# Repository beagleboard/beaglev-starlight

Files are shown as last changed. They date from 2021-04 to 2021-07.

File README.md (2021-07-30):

## ARCHIVED: BeagleV™ - Starlight beta prototype
The BeagleV™ - Starlight project has concluded and no units beyond the beta prototypes will be produced.  This design was never sold as a product.  

**This repository is meant only for archival purposes.**  Please do not open any new issues.  

Please visit the [BeagleV™ community website](http://beaglev.org/) to learn about future RISC-V development boards.

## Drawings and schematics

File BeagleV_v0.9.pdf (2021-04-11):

# VIC Power

# PMIC

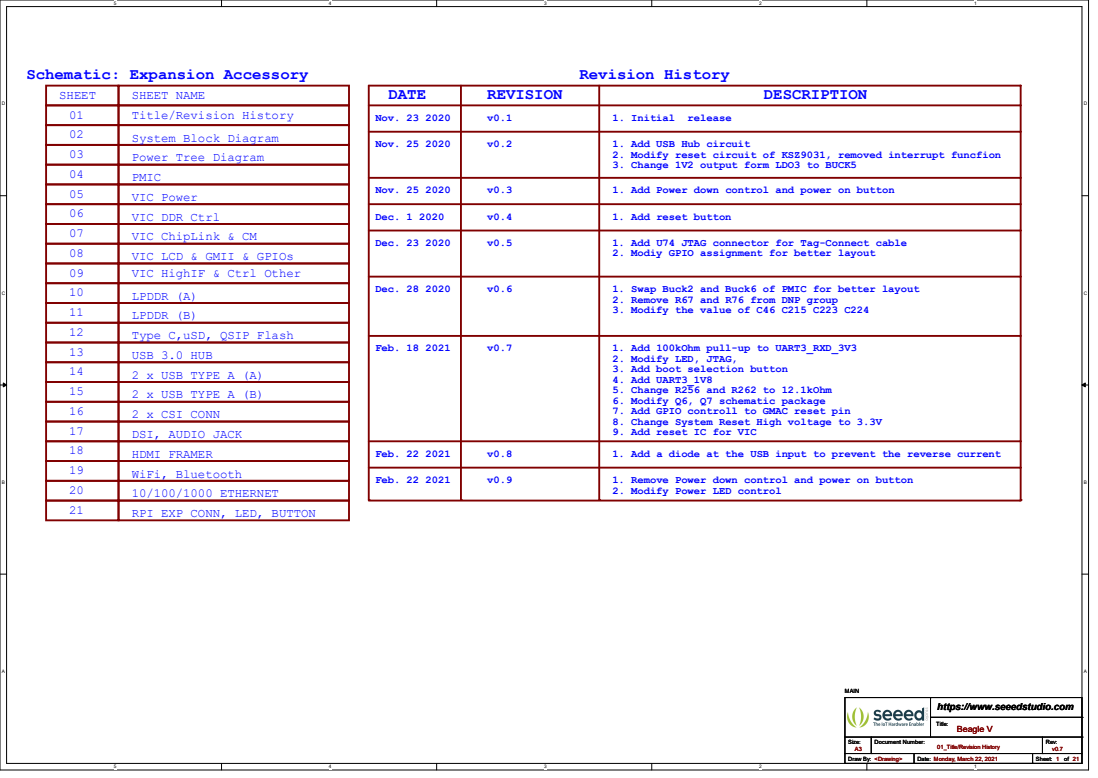
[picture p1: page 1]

Nov. 23 2020 | v0.1 | 1. Initial release

Nov. 25 2020 | v0.2 | 1. Add USB Hub circuit 2. Modify reset circuit of KSZ9031, removed interrupt funcfion 3. Change 1V2 output form LDO3 to BUCK5

Nov. 25 2020 | v0.3 | 1. Add Power down control and power on button

VIC DDR Ctrl
VIC ChipLink & CM
VIC LCD & GMII & GPIOs
VIC HighIF & Ctrl Other
LPDDR (A)
LPDDR (B)
Type C,uSD, QSIP Flash
USB 3.0 HUB
2 x USB TYPE A (A)
2 x USB TYPE A (B)
2 x CSI CONN
DSI, AUDIO JACK
HDMI FRAMER
WiFi, Bluetooth
10/100/1000 ETHERNET
RPI EXP CONN, LED, BUTTON

Dec. 1 2020 | v0.4 | 1. Add reset button

Dec. 23 2020 | v0.5 | 1. Add U74 JTAG connector for Tag-Connect cable 2. Modiy GPIO assignment for better layout

2. Remove R67 and R76 from DNP group
3. Modify the value of C46 C215 C223 C224

Feb. 18 2021 | v0.7 | 1. Add 100kOhm pull-up to UART3_RXD_3V3 2. Modify LED, JTAG, 3. Add boot selection button 4. Add UART3_1V8 5. Change R256 and R262 to 12.1kOhm 6. Modify Q6, Q7 schematic package 7. Add GPIO controll to GMAC reset pin 8. Change System Reset High voltage to 3.3V 9. Add reset IC for VIC

Feb. 22 2021 | v0.8 | 1. Add a diode at the USB input to prevent the reverse current

2. Modify Power LED control

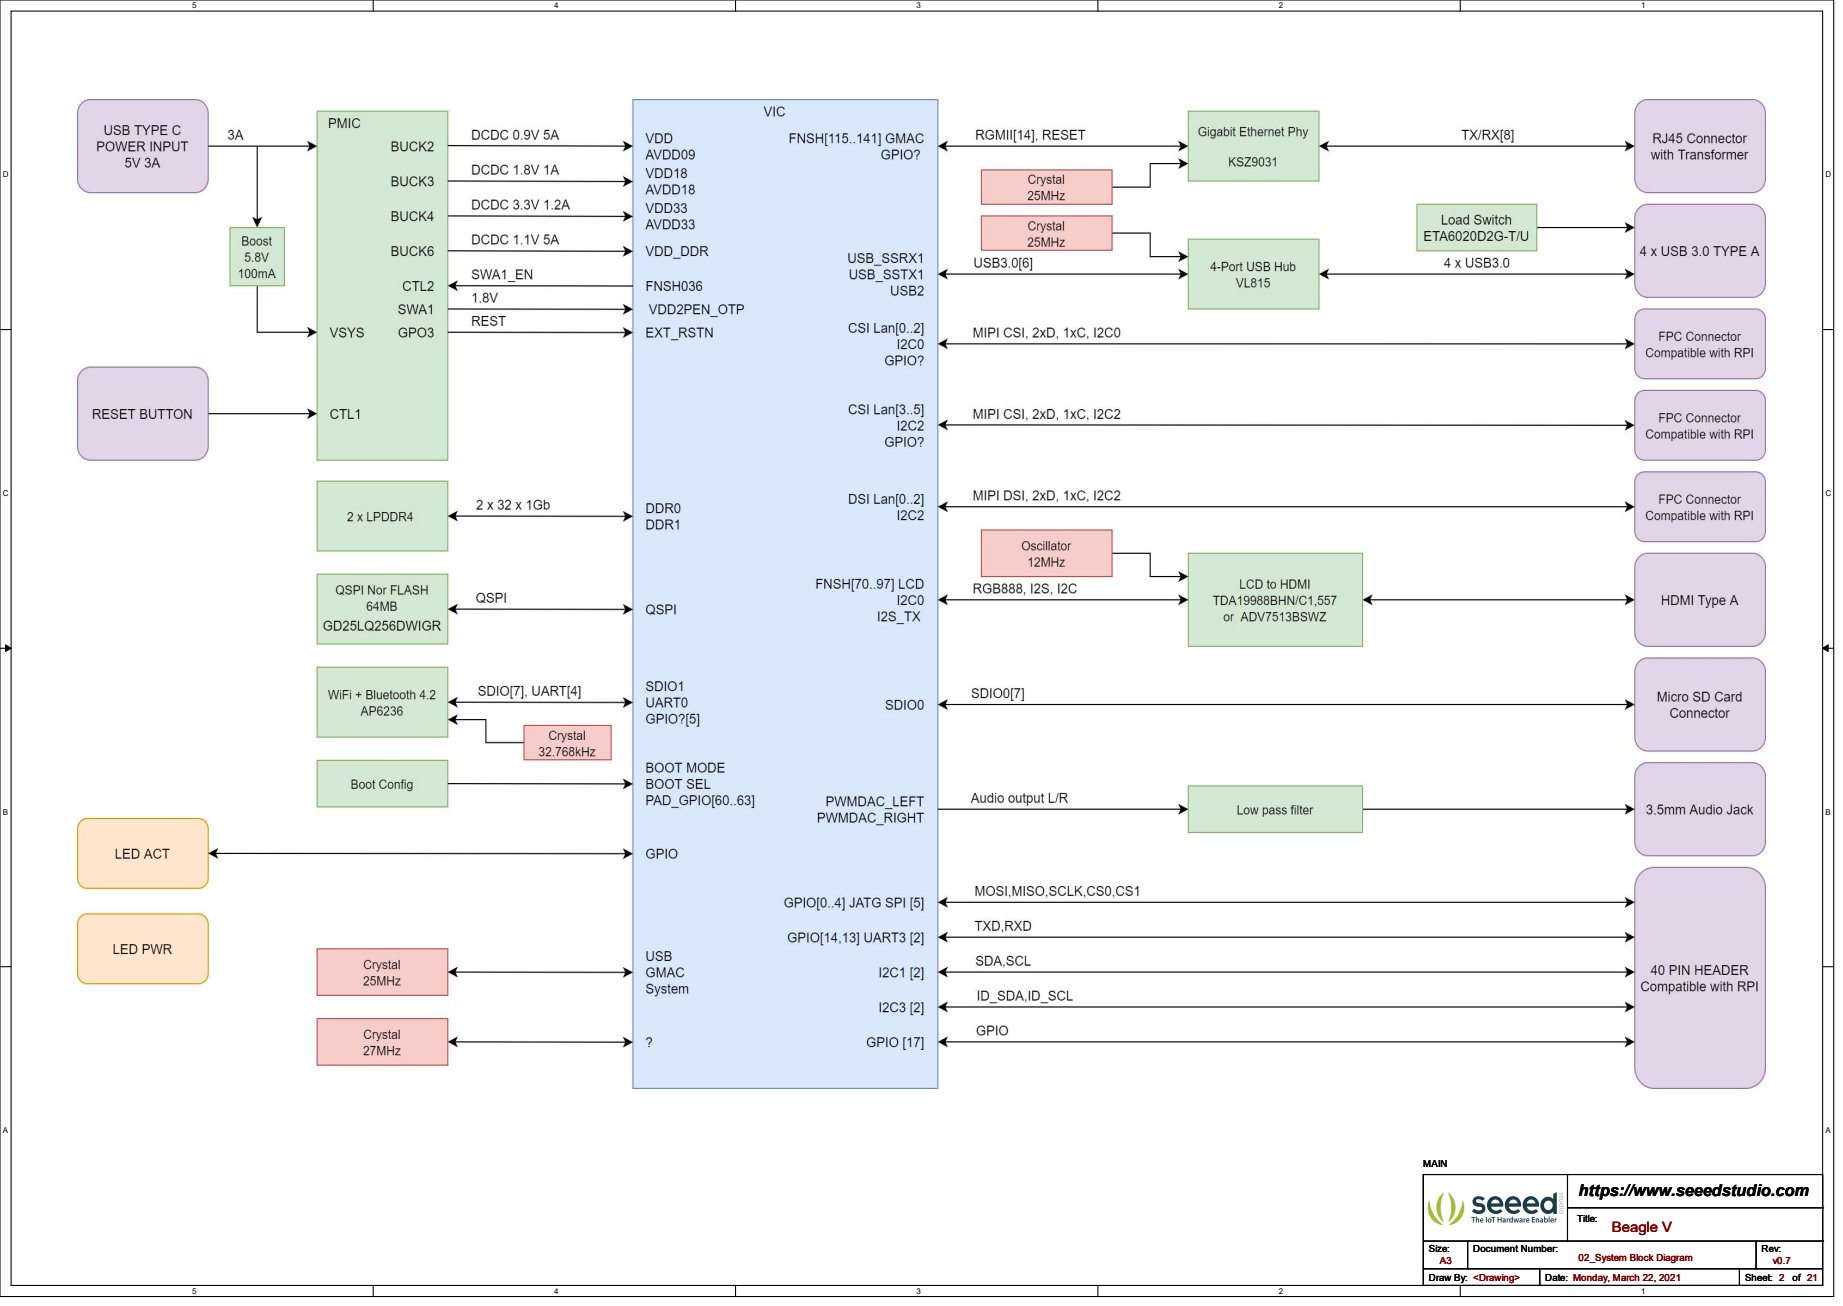
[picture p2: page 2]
A Title: Size:; Document Number:; Rev: Draw By:; Date:; Sheet:; https://www.seeedstudio.com A3; v0.7 <Drawing>; Monday, March 22, 2021; 21 Beagle V; 02_System Block Diagram; MAIN

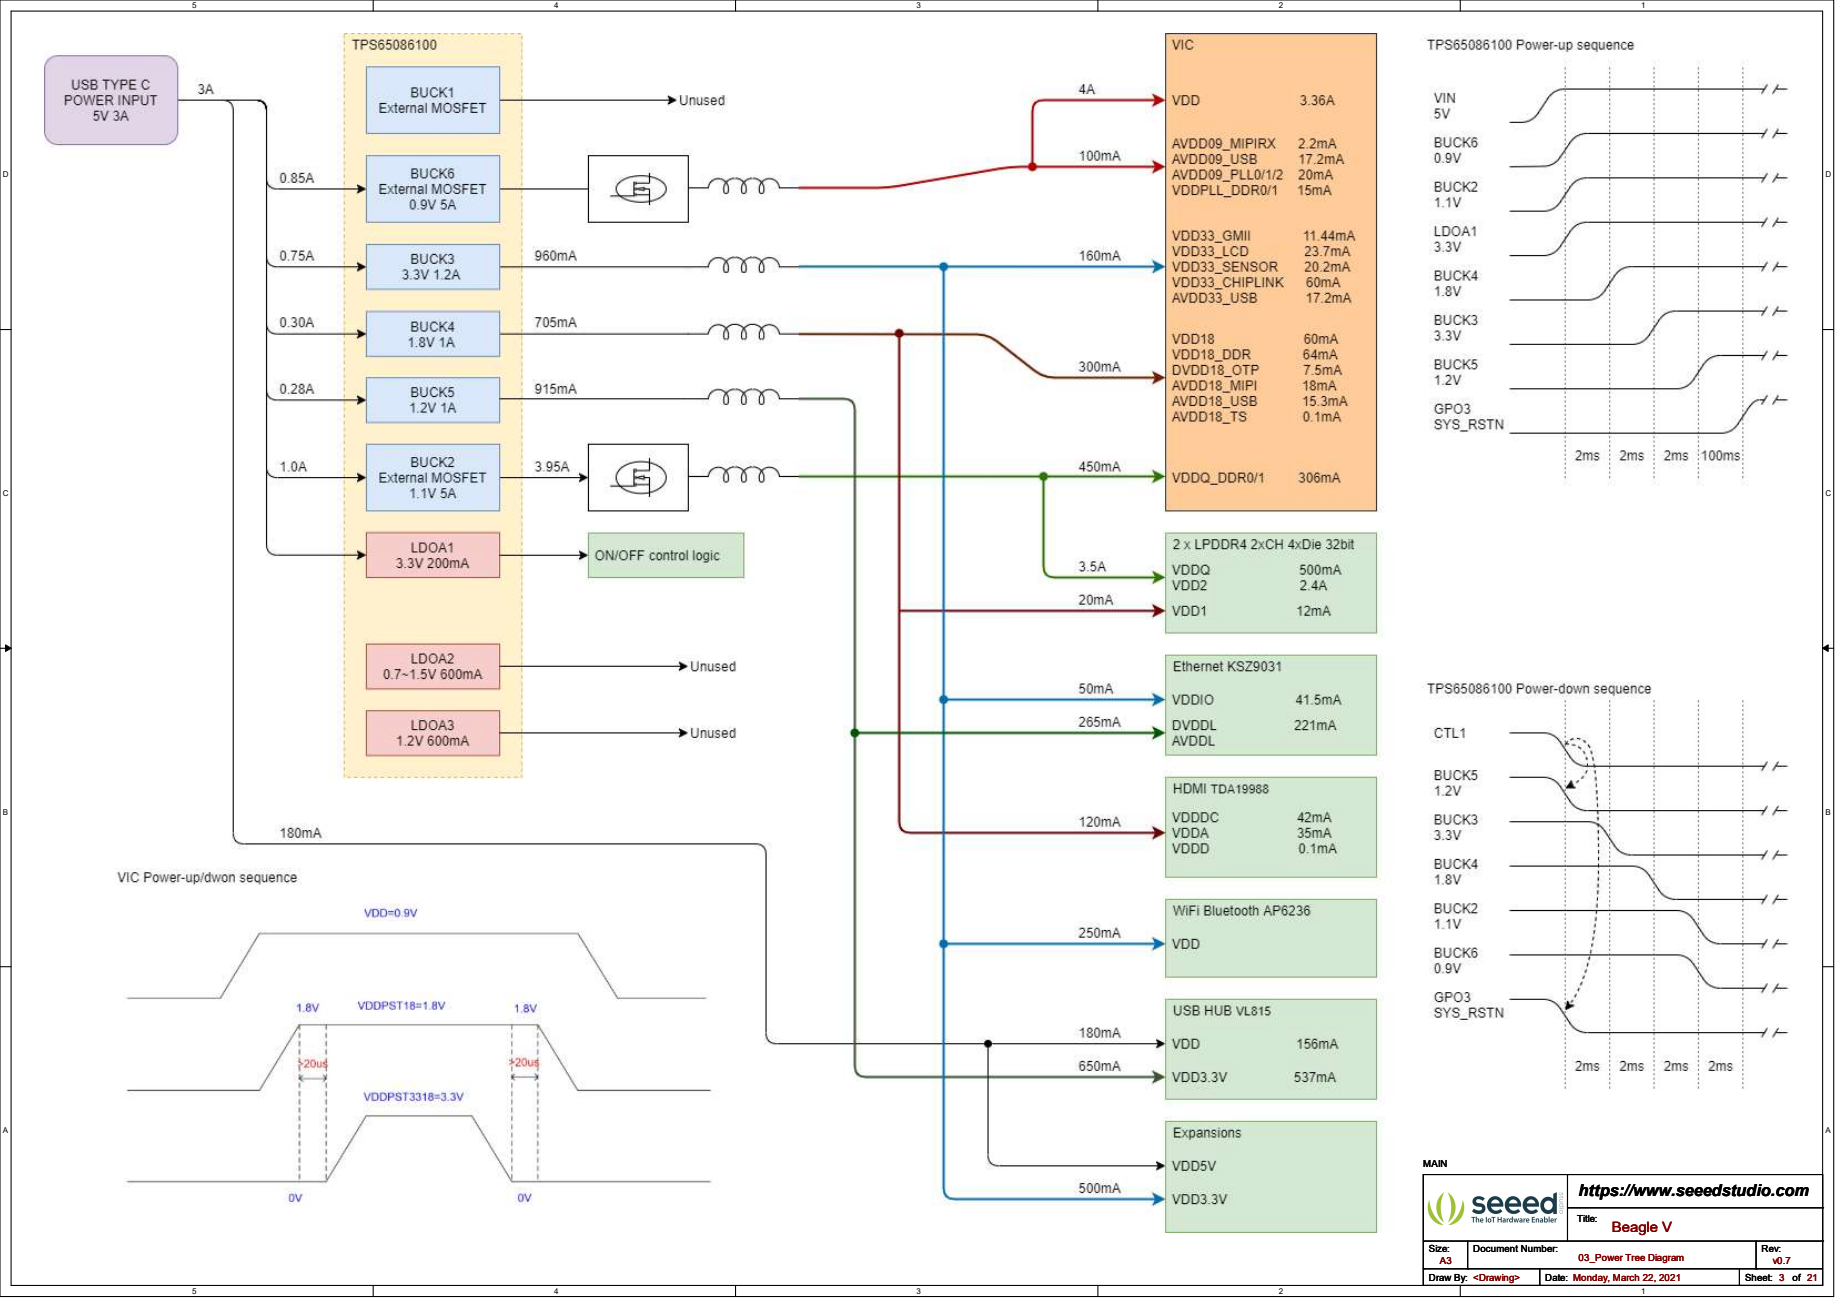
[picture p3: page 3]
A Title: Size:; Document Number:; Rev: Draw By:; Date:; Sheet:; https://www.seeedstudio.com A3; v0.7 <Drawing>; Monday, March 22, 2021; 21 Beagle V; 03_Power Tree Diagram; MAIN

# Step-Up for PMIC

# PMIC

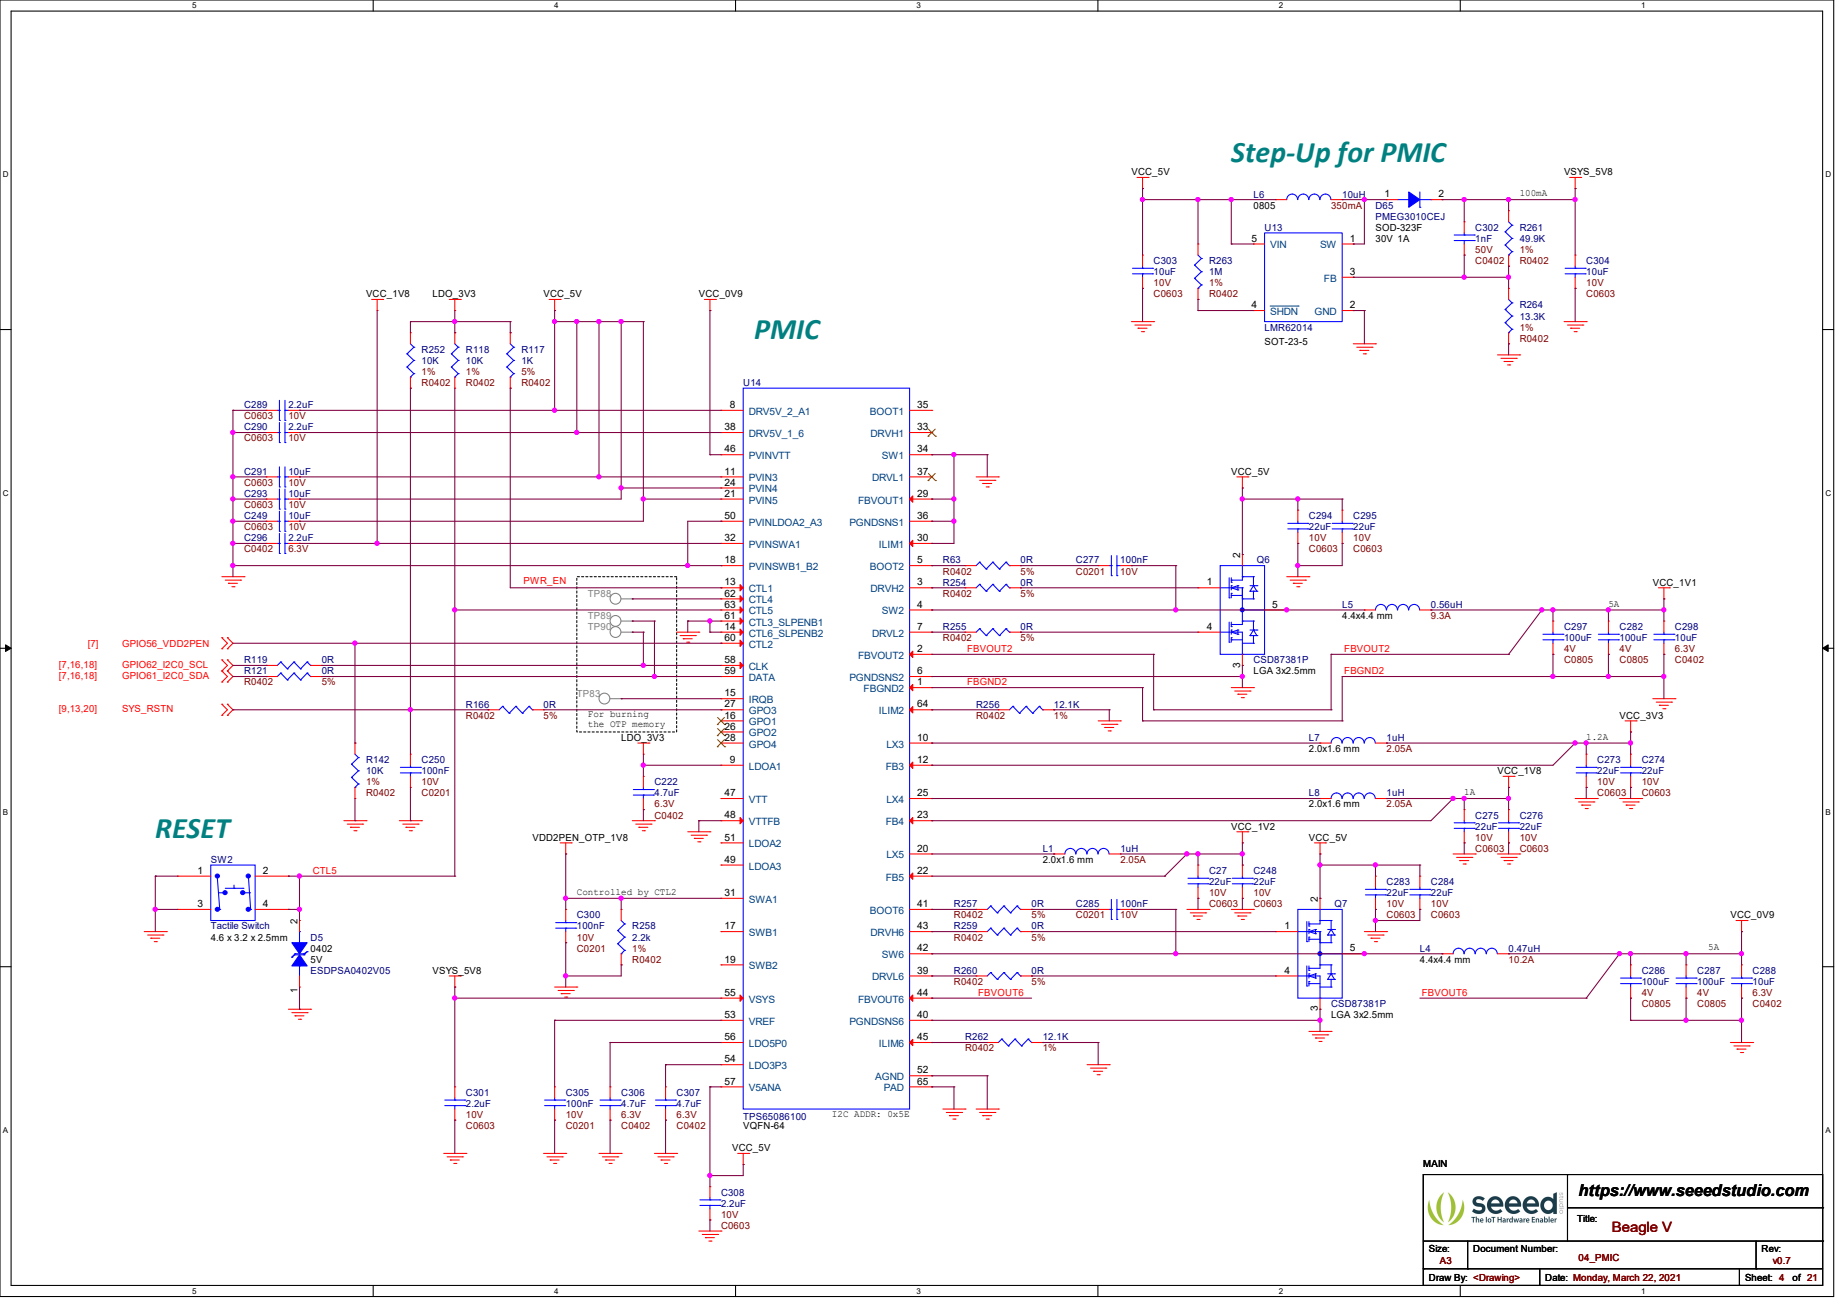
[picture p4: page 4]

VSS000 A4 VSS001 A7 VSS002 A11 VSS003 A18 VSS004 B21 VSS005 C1 VSS006 D2 VSS007 D9 VSS008 D23 VSS009 E2 VSS010 E17 VSS011 F7 VSS012 F16 VSS013 F20 VSS014 F24 VSS015 G3 VSS016 G13 VSS017 G16 VSS018 G20 VSS019 G22 VSS020 H7 VSS021 H9 VSS022 H10 VSS023 H16 VSS024 H17 VSS025 H18 VSS026 H20 VSS027 J9 VSS028 J10 VSS029 J12 VSS030 J16 VSS031 J17 VSS032 J22 VSS033 J23 VSS034 K3 VSS035 K5 VSS036 K8 VSS037 K9 VSS038 K10 VSS039 K11 VSS040 K22 VSS041 K23 VSS042 K25 VSS043 L8 VSS044 L9 VSS045 L10 VSS046 L11 VSS047 L12 VSS048 L13 VSS049 L16

VSS050 L18 VSS051 L19 VSS052 L20 VSS053 L22 VSS054 L23 VSS055 M10 VSS056 M11 VSS057 M12 VSS058 M13 VSS059 M14 VSS060 M15 VSS061 M16 VSS062 M17 VSS063 M18 VSS064 M20 VSS065 M22 VSS066 M24 VSS067 N3 VSS068 N12 VSS069 N15 VSS070 N16 VSS071 N17 VSS072 N18 VSS073 N20 VSS074 N22 VSS075 N25 VSS076 P12 VSS077 P14 VSS078 P15 VSS079 P18 VSS080 P20 VSS081 P22 VSS082 P24 VSS083 R12 VSS084 R14 VSS085 R15 VSS086 R20 VSS087 R22 VSS088 R23 VSS089 T3 VSS090 T9 VSS091 T10 VSS092 T11 VSS093 T12 VSS094 T14 VSS095 T22 VSS096 T24 VSS097 T25 VSS098 U8 VSS099 U9 C132

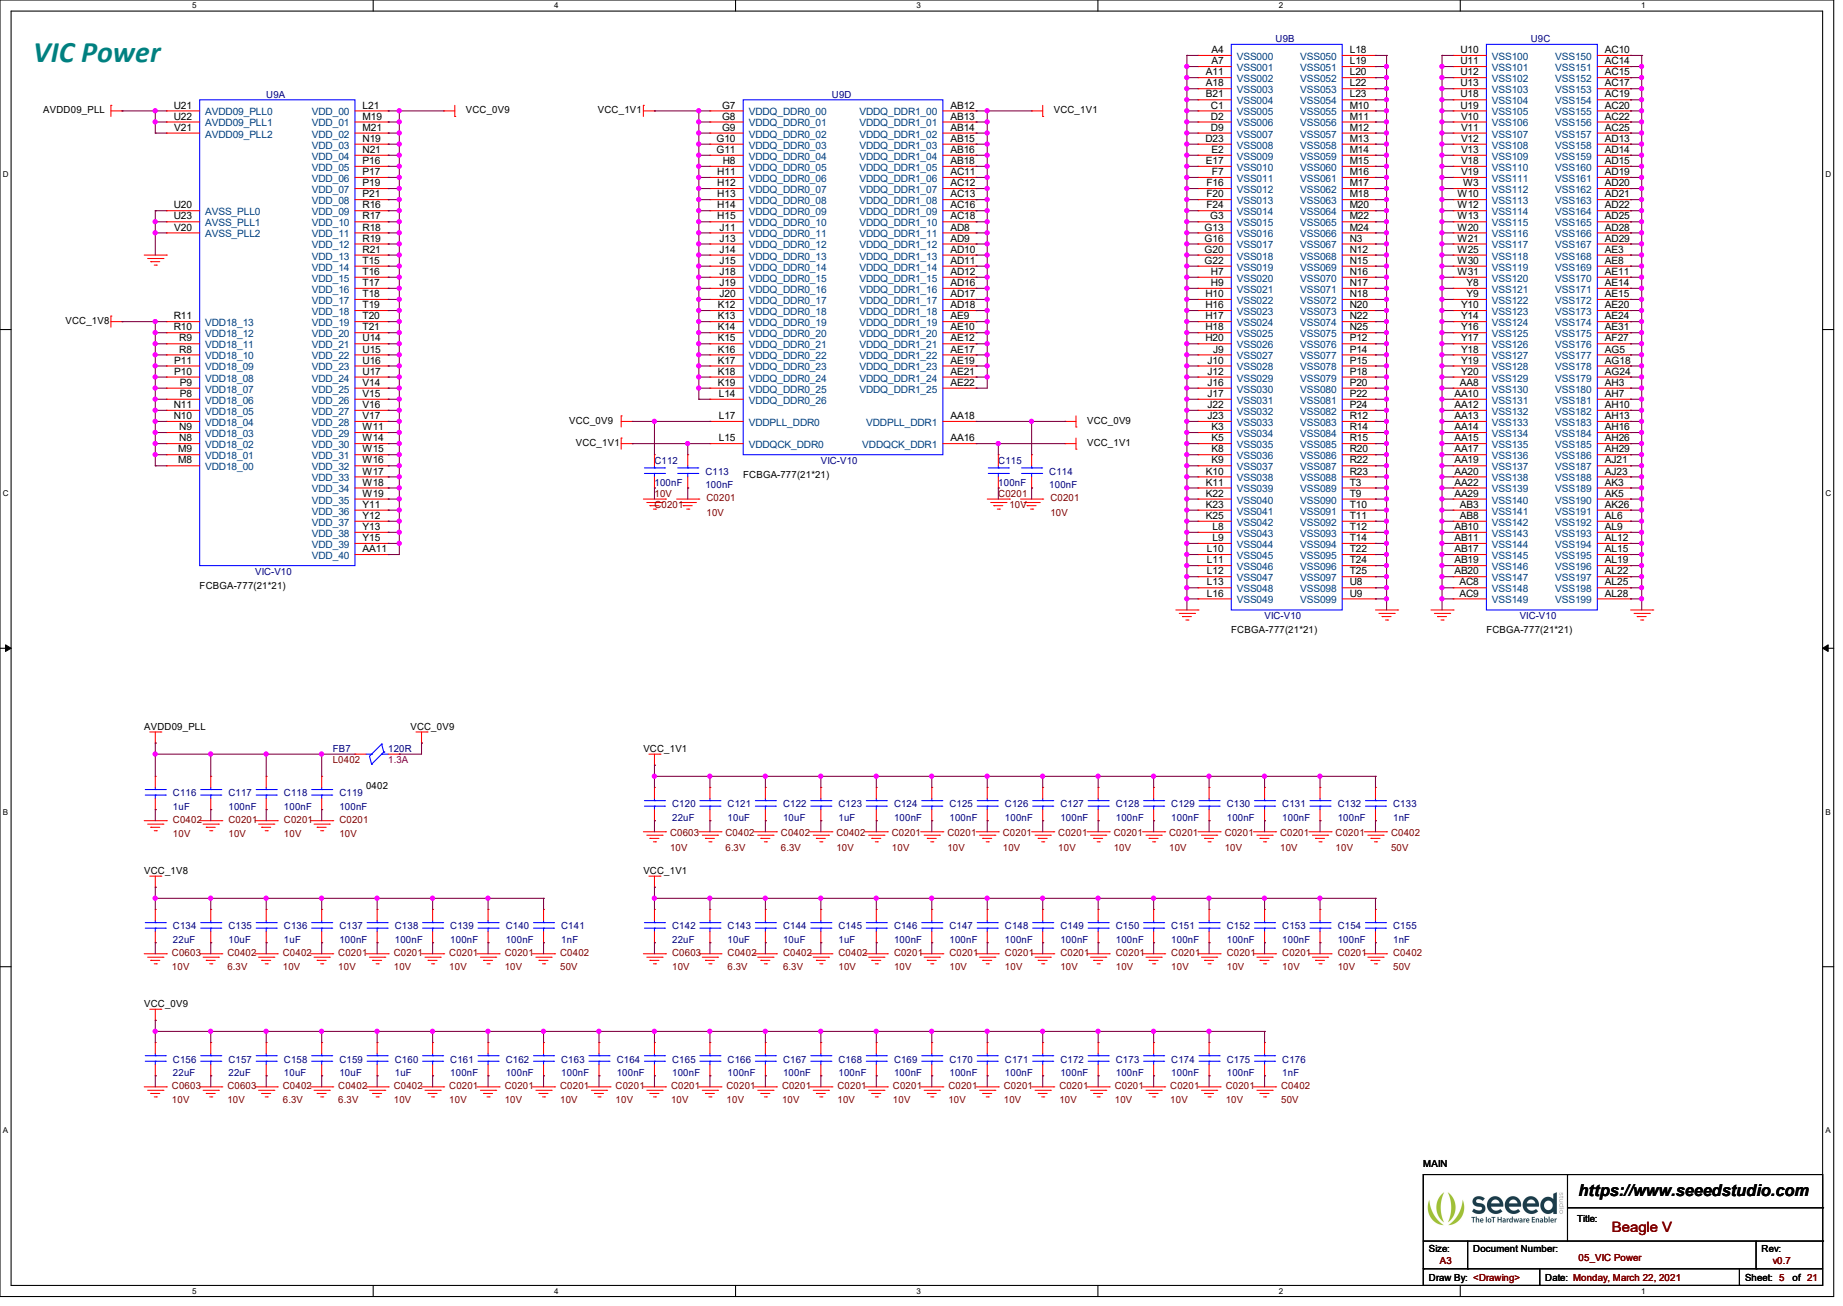
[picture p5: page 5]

# VIC DDR controller

DDR0_DQ00 | [10] DDR0_DQ01 | [10] DDR0_DQ02 | [10] DDR0_DQ03 | [10] DDR0_DQ04 | [10] DDR0_DQ05 | [10] DDR0_DQ06 | [10] DDR0_DQ07 | [10] DDR0_DQ08 | [10] DDR0_DQ09 | [10] DDR0_DQ10 | [10] DDR0_DQ11 | [10] DDR0_DQ12 | [10] DDR0_DQ13 | [10] DDR0_DQ14 | [10] DDR0_DQ15 | [10] DDR0_DQ16 | [10] DDR0_DQ17 | [10] DDR0_DQ18 | [10] DDR0_DQ19 | [10] DDR0_DQ20 | [10] DDR0_DQ21 | [10] DDR0_DQ22 | [10] DDR0_DQ23 | [10] DDR0_DQ24 | [10] DDR0_DQ25 | [10] DDR0_DQ26 | [10] DDR0_DQ27 | [10] DDR0_DQ28 | [10] DDR0_DQ29 | [10] DDR0_DQ30 | [10] DDR0_DQ31 | [10]

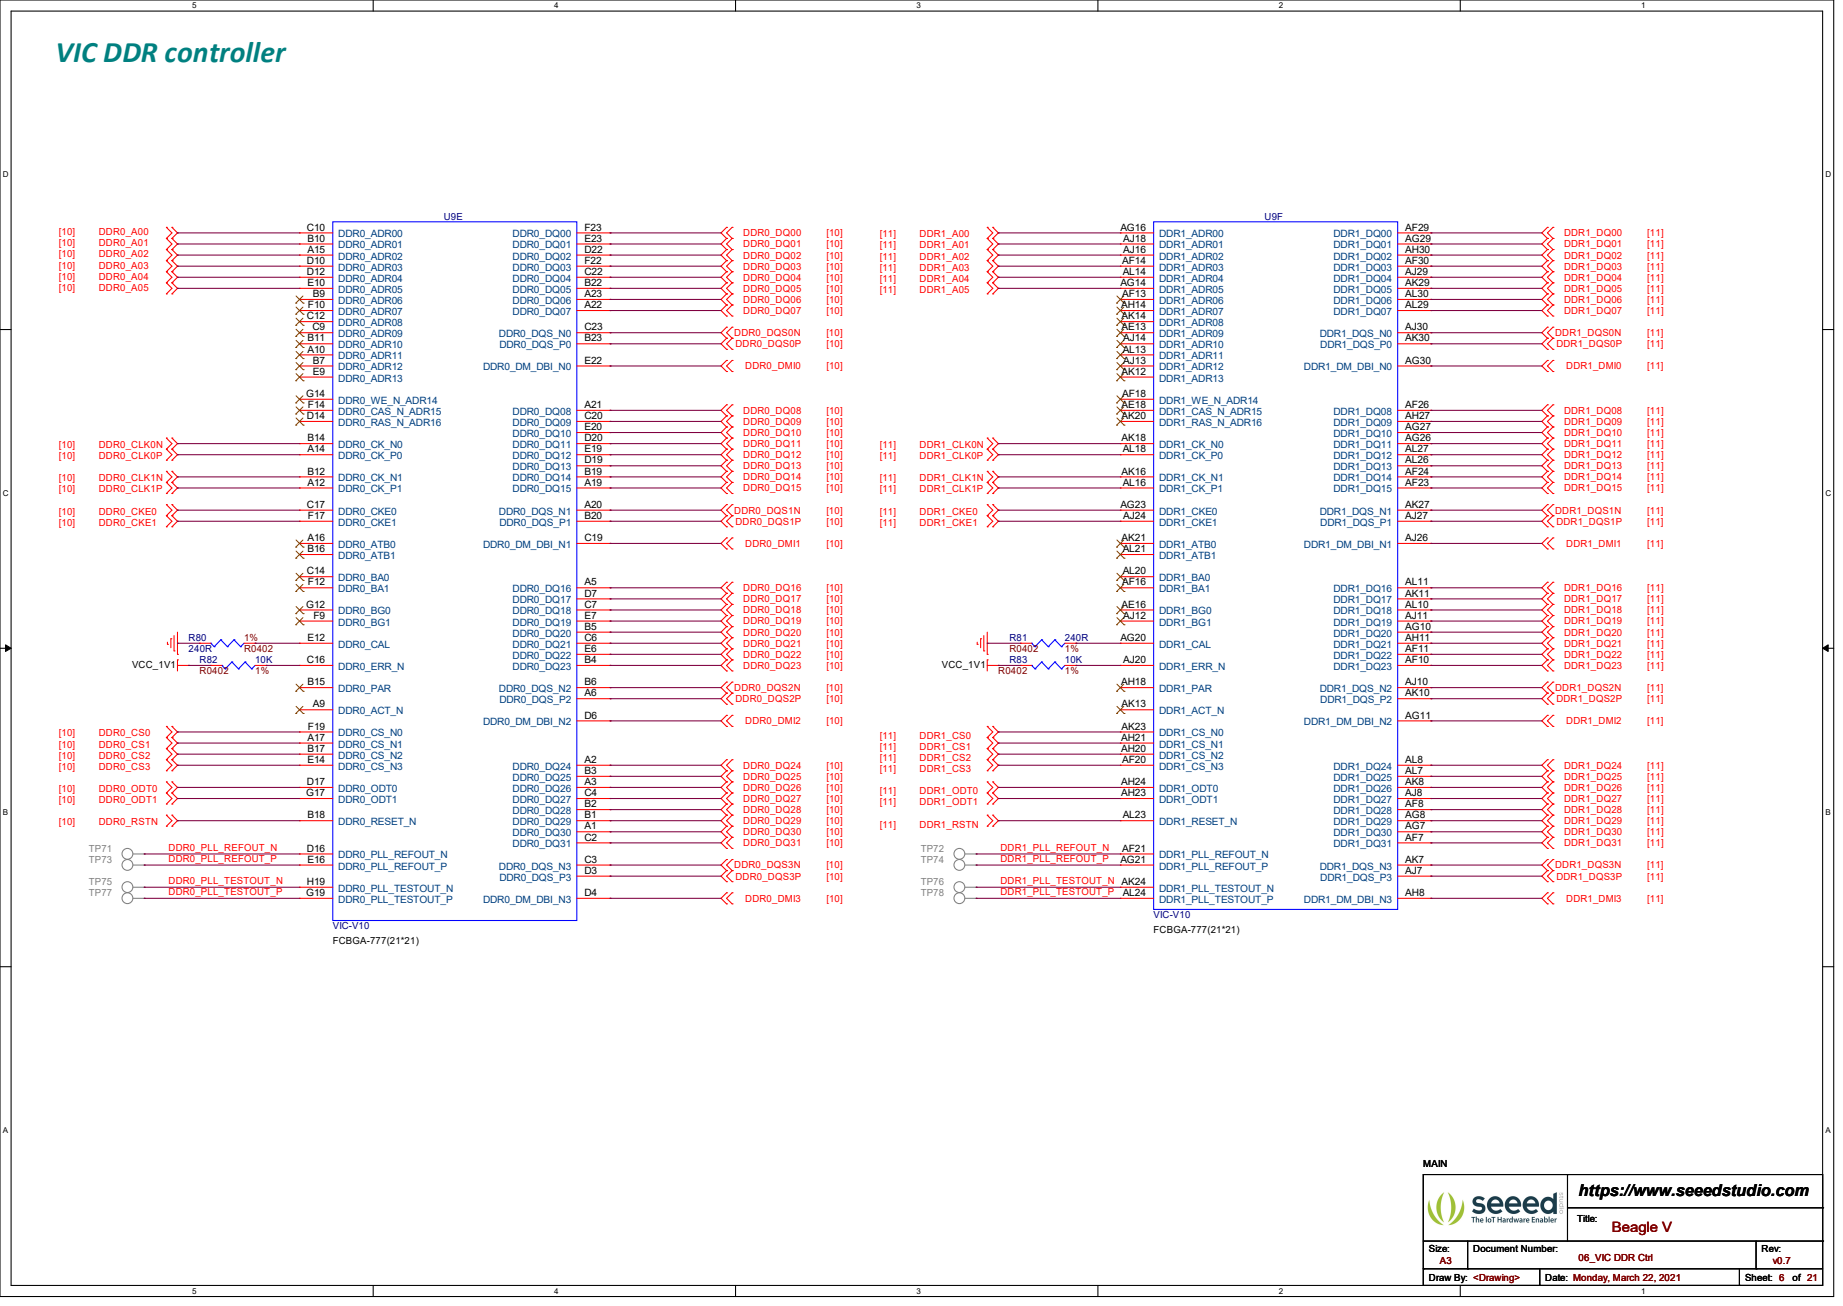
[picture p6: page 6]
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

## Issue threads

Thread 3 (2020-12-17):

RV Pi: question: will USB perform dual-role function?

jadonk, 2020-12-17:
Currently, the USB type-C is only capable of providing power. Further, the superspeed USB is only provided via 2 Type-A connectors. I think this is a huge limitation if the controller is dual-role capable.

It seems there is only one USB controller exposed and it goes to an on-board HUB, so that could dedicate it to being host-only all the time.

If nothing else, you could at least connect a USB to serial MCU via the Type-C connector to get to the debug console for a nice out-of-box for headless Linux users.

More thought needed here.

Closed 2021-03-31.

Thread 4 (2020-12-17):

HW: question/thought: how do you access the console UART?

jadonk, 2020-12-17:
This is a fundamental requirement for Linux kernel and u-boot developers.

I recommend using the UART connector on the BeagleBone AI or adding a USB-to-UART MCU. If you include the MCU, having the ability to power-down the board while the UART is connected is very useful.

Closed 2021-03-31.

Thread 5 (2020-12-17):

RV Pi: question/thought: how do we avoid bricking?

jadonk, 2020-12-17:
It seems that SPI is used for booting.

Are there any provisions for re-programming the SPI Flash? What happens if bad contents are programmed into the SPI Flash?

What boot modes are supported by the SoC ROM?

Is it possible to use a "BOOT button" similar to BeagleBone to enable UART/MMC/other boot based on the ROM bootloader?

Closed 2021-03-31.

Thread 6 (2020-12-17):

RV Pi: question: can we make it look less like a Raspberry Pi?

jadonk, 2020-12-17:
* What is the real functionality of the Pi header in terms of compatible functionality?
* Can we replace the header with a number of Grove and mikroBUS Click Shuttle headers (https://www.mikroe.com/shuttle-click)?

Closed 2021-03-31.

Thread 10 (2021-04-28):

Insufficient clearance on mounting holes

pdp7, 2021-04-28:
From @marckleinebudde in the [forum](http://forum.beagleboard.org/):
> the clearance on the raspi compatible mounting holes is not that great. Also having copper around the holes would be good, too.
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

mitag, 2021-04-28:
As a workaround, you could perhaps replace the M 2.5 spacers with M 2 spacers and place a nylon washer underneath.

FionaYu20180326, 2021-04-29:
> As a workaround, you could perhaps replace the M 2.5 spacers with M 2 spacers and place a nylon washer underneath.
Thanks for your feedback. This is a mounting hole compatible with raspberry pi. We will modify this design to move the chip.

marckleinebudde, 2021-04-29:
It even works with the metal spacer. If I'm careful the spacer doesn't touch any pins of the chip. Just make sure it's fixed in the next board revision.

Closed 2021-07-30.

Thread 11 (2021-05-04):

suggestion to improve debug header signal levels

pdp7, 2021-05-04:
@bbbsnowball commented:
> The “Recover the bootloader” section shows a normal 3.3V USB-TTL adapter connected to the debug header. The signals on that header are labelled as 1V8. I think this ok anyway because there is a level shifter for RX (built with a pullup and a diode). However, be sure to get the connections right because there is a higher chance than usual to damage the SoC by connecting TX to TX. In addition, it is possible (but unlikely) that the TX levels are too low for some 3.3V adapters. We might want to collect some feedback on whether the usual ones (CH340, Prolific, FTDI) are ok.
>
> The debug header is not populated on my board. If this is normal, you might want to mention that in the guide.

refer to forum post:
https://forum.beagleboard.org/t/update-bootloader-ddr-init-boot-u-boot-and-recover-bootloader/29558/7
(let me [Drew] know if you don't have access)

BBBSnowball, 2021-05-04:
Thanks. Just to be clear about this: I don't consider this a bug. This kind of cheap level shifter is well suited for the UART.

I only suggest that we could add some information to the guide:
1. Make sure to get the connections right! And maybe some guidance on how to measure which pin is RX/TX. Unfortunately, some adapters label it as "this is TX" and others as "connect this pin to TX" so you can't trust the labels.
  - Most adapters probably won't drive enough current to actually damage the SoC.
  - The most obvious labels are RX and TX plus an arrow that shows the data direction. We could add those to the board silk screen but there is hardly any space for it - and we would need the same labelling on the UART adapter.
2. This should work with any 3.3V adapter but there is a slight chance that it doesn't. If so, try another one. The following are known to work: ...

Both issues are only in theory. We can very well ignore them until we have some evidence that they can happen in practice.

BBBSnowball, 2021-05-07:
There is a [report](https://forum.beagleboard.org/t/beaglev-starlight-beta-development-report/29641/12) that PL2303 is not working. [The datasheet](https://cdn-shop.adafruit.com/datasheets/PL2303HX.pdf) says that an input should be at least 70% of VCC to be seen as high, which is 2.3V. 70% is a very common value so I assume that it is not the actual limit. However, 1.8V seems to be too low.

I recommend that we document the issue and don't change the board because most users won't use the debug header and advanced users will likely have more than one type of UART adapter.

pdp7, 2021-05-07:
Thank you.  @lakshanthad could you add to the getting started?

BBBSnowball, 2021-05-07:
CP2102 is [reported to be fine](https://forum.beagleboard.org/t/update-bootloader-ddr-init-boot-u-boot-and-recover-bootloader/29558/12). [FTDI, as well](https://forum.beagleboard.org/t/update-bootloader-ddr-init-boot-u-boot-and-recover-bootloader/29558/15).

lakshanthad, 2021-05-10:
> Thank you. @lakshanthad could you add to the getting started?

Yes I will @pdp7

lakshanthad, 2021-05-10:
> CP2102 is [reported to be fine](https://forum.beagleboard.org/t/update-bootloader-ddr-init-boot-u-boot-and-recover-bootloader/29558/12). [FTDI, as well](https://forum.beagleboard.org/t/update-bootloader-ddr-init-boot-u-boot-and-recover-bootloader/29558/15).

https://beagleboard.slack.com/archives/C01QV90F5KM/p1620581877127100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

pdp7, 2021-05-19:
@FionaYu20180326  @lakshanthad concerns from [Akira in the forum](https://forum.beagleboard.org/t/soldering-debug-port-for-boatloader-recovery/29819/8):
> I just checked the schematics of the BeagleV and GPIO13/UART3_RX_1V8 (1.8v) from jh71x0 soc is directly connected to 40pin-Pi-Connector by pull-up register with 3.3v to convert it from 1.8v but the debug serial port has pull-up register with 1.8v which means it is expecting 1.8v logic level instead of 3.3v, so this will cause logic level mismatch and worse case, it will damage the jh71x0 SoC. I will try 1.8v logic level USB-serial converter. Connecting 3.3v usb-serial converters to 1.8v debut serial port is dangerous.

>  Is it possible to ask Seeed to revise the schematics on the product version of the BeagleV to use both 3.3v logic level for both 40-pin-Pi-Connector and debug serial port? Expecting the developers to buy both 3.3v and 1.8v usb-serial adapters are a bit high boundaries.

> And I am not so sure how the schottky diode (D6 PMEG3010CEJ) used on UART3_RXD_1V8 for the protection. It looks like the schottky diode (D6 PMEG3010CEJ) was meant to be in between UART3_TXD_1V8 and pin3 of J14. If I have a time this weekend I will trace with my scope.

mcd500, 2021-05-20:
@BBBSnowball taught me at the forum that the schottky diode (D6 PMEG3010CEJ) is for a level shifter to convert 3.3V TX signal from the  adapter to 1.8V SoC input. The forward voltage of the diode is only 330mV at 100 mA, it is a nice design keeping the BOM cost low.

mcd500, 2021-05-20:
@FionaYu20180326 @lakshanthad, As @BBBSnowball mentioned, as long as the developer does not connect the 3.3V TX output of the adapter to the RX input on the board, then it will not damage the board and it is ok.
I checked the datasheets of CP2102 and while FTDI and CP2102 expects 2.0V min to detect as high (Vih) and it is 1.5V for FTDI, the output of 1.8V level from  jh71x0 SoC to be detected as a high at adapter chips it is kind of pushing the limit of the datasheet of the usb-serial chips.
I prefer having a level shifter on both UART3_TXD_1V8 and UART3_RXD_1V8 to have more margins but it is up to the decision of the Seeed.

mcd500, 2021-05-20:
@FionaYu20180326 @lakshanthad @BBBSnowball I listed all four chips, cp2102, ftdi, ch340, pl2303 at the forum. https://forum.beagleboard.org/t/usb-to-serial-adapters-known-to-work/29798
I have two ftdi 3.3v adapters and both worked on a 1.8v debug serial converter as well as one of my cp2101.

Closed 2021-07-30.

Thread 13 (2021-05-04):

Minor typo in schematic

robertlipe, 2021-05-04:
In https://github.com/beagleboard/beaglev-starlight/blob/main/BeagleV_v0.9.pdf on sheet 12 of 17, there is a typo in the page name. It's titled "USB Tpye-C Power", which is a simple transposition error for "Type".

This is about the limit of my ability to recognize a bug in a schematic of this complexity. :-)

Closed 2021-07-30.

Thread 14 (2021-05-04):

Enable TPS65086 restart interrupt

pdp7, 2021-05-04:
@esmil worked on TPS65086 restart in their [Linux 5.12 branch](https://github.com/esmil/linux/tree/starlight) and noticed that it would work better if the interrupt line from the TPS65086 was connected.

@esmil could you describe in more detail?

We will try to fix in the next PCB spin.

esmil, 2021-05-04:
The TPS65086 has an output pin IRQB (open-drain, needs pull-up) to signal an interrupts. This should be routed to a GPIO pin on the SoC that can be set up to generate an interrupt when the TPS65086 pulls the line low.

Note however, that 7V is needed on IRQB when programming the OTP memory on the TPS65086, so if this might damage the SoC and the TPS65085 is programmed in-circuit some solution must be found.

(Btw. thanks for the consideration, but him/his is fine. I'm just a regular boring straight white nerd :P)

pdp7, 2021-06-08:
@FionaYu20180326 This issue is about allowing the PMIC to signal Linux that the system is going to be reset.  @esmil noticed that TPS65086 has an output pin IRQB (open-drain, needs pull-up) to signal an interrupt. This should be routed to a GPIO pin on the SoC that can be set up to generate an interrupt when the TPS65086 pulls the line low.

Closed 2021-07-30.

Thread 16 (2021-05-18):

v0.9 is missing GPIO63 to trigger CTRL1 on the PMIC

pdp7, 2021-05-18:
@michaelzhuxx commented:
https://github.com/starfive-tech/Fedora_on_StarFive/issues/25#issuecomment-840228593
> we found the reason why our board could reset and beta board couldnt is that the schematic is updated. the beta board is remove the GPIO63 to trigger "CTRL1" on the pmic. Attached two version of schematic for your reference. @esmil thanks. we will fix it.

pdp7, 2021-05-18:
@esmil is CTRL1 related to IRQB in #14?

esmil, 2021-05-18:
Not directly. In the v0.9 schematic the pmic has an output pin, GPO3, connected to the reset lines of the SoC, USB usb hub and the ethernet phy. The pmic also has a number of input pins CTL1 - CTL6. As far as I can tell the GPO3 output is set up to go high when the different voltage levels are good **and** CTL1 is high **and** CTL5 is high.

Both CTL1 and CTL5 are pulled high by the "LDO_3V3" power line, but the physical reset button is set up to pull CTL5 low when the button is pressed. This then results in the GPO3 output going low and thus resetting the SoC, USB hub and ethernet phy.

Having GPIO63 set up to pull CTL1 low would then reset the everything the same way as the physical button just signalling CTL1 instead of CTL5.

However the way I reset the board in my [starlight][] branch is that I just tell the pmic to reset itself over the I2C connection. This way the pmic also pulls GPO3 low while it goes through the startup sequence of turning on he different power rails and signalling "power good" by releasing GPO3 again.

So with this code in place we don't actually need GPIO63 to trigger CTL1 since telling the pmic to reset itself over I2C should pull GPO3 low and reset the SoC, USB hub and ethernet phy in exactly the same way. I'd rather have the IRQB line fixed so we can get interrupts from the pmic as described in #14. Having both won't hurt though.

rvs, 2021-05-18:
Wait, @esmil -- but it sounds like it almost works "by accident" (not that I'm complaining that it does!) so my question is -- shouldn't the board have an *explicit* "officially supported" reset functionality?

esmil, 2021-05-18:
I'm not sure why you think it sounds like it works by accident. I'm sure the board is designed such that the pmic "power good" output is connected to the various reset lines exactly such that they're kept in reset mode until the pmic upstart sequence is done an power levels are stable. I'm sure we can agree that the board resetting properly after being turned on is not "by accident", and resetting the pmic (by I2C) should work exactly the same way.

rvs, 2021-05-18:
> I'm sure we can agree that the board resetting properly after being turned on is not "by accident"

absolutely!

> and resetting the pmic (by I2C) should work exactly the same way

I agree that for as long as pmic is guaranteed to have that API (the I2C one) -- we're all good. I'm not just not enough into pmic's to know whether this is something that is expected to be a basic functionality of a pmic. Hence my question.

esmil, 2021-05-18:
> > and resetting the pmic (by I2C) should work exactly the same way
>
> I agree that for as long as pmic is guaranteed to have that API (the I2C one) -- we're all good.

Yes, it has a (badly named) register just for this,

pdp7, 2021-06-08:
@tekkamanninja @michaelzhuxx please help update my explanation so that it is clear to @FionaYu20180326 what change we would like to see in the next PCB revision to allow GPIO reset to work

pdp7, 2021-06-08:
@FionaYu20180326 this is the problem the @michaelzhuxx [found](https://github.com/starfive-tech/Fedora_on_StarFive/issues/25#issuecomment-840228593) which should be fixed:
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

qunanan, 2021-06-10:
@esmil
Hi emil,
Here is the sequencing setup of the PMIC. CTL1 is the enable signal of all the power rails. CTL5 just affects the GPO3 of PMIC.

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

Closed 2021-07-30.

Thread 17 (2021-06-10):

request for part information for KiCad conversion

pdp7, 2021-06-10:
@FionaYu20180326 would you be able to help @aswinvenu ?

He recreating the schematic in KiCad:
https://gitlab.com/aswinvenu/beaglev-kicad

He is trying to find information on:
1. UBF31-0171 - USB Type C connector from MTCONN
2. UAA111C-84161-4H - Dual Stacked USB3.0 Type A from FOXCONN
3. ST-HD-010 - HDMI connector from SHANQI
4. H9HCNNNCPUMLXR-NEE - 32Gb RAM from Hynix

This is also a post in the forum:
https://forum.beagleboard.org/t/beaglev-kicad/30006/6?u=drewfustini

FionaYu20180326, 2021-06-15:
I asked aswinvenu to share email address to me on Beagleboard forum.

  _____

Best Regards

Fiona Yu (余凤)  Project Manager

Seeed Technology Co., Ltd.

TEL:  +86 -186 8870 1862

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

Closed 2021-07-30.

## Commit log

2020-12-17 Files from Fiona
    This is the intitial StarFive 7100 R-Pi style board.
    [STARLIGHT MODEL 01.DSN]
2020-12-30 Rename to BeagleV
    Also minor cleanup to schematic and GPIO labels.
    [202003182_PCBABeagleV_A4_1228.xlsx, Beagle V.DSN, STARLIGHT MODEL 01.DSN]
2021-04-11 Add current version of the BeagleV beta board
    This includes Cadence OrCad and Allegro files along with PDF. I also
    added screenshot of viewing BeagleV in Allegro Viewer. Cadence Allegro
    Viewer can be downloaded from:
    https://www.cadence.com/en_US/home/tools/pcb-design-and-analysis/allegro-downloads-start.html
    I also compressed BeagleV_15.brd as it is over 100MB
    [BeagleV v0.9.DSN]
2021-04-22 update BeagleV Starlight beta board desgin
    [202003182_PCBABeagleV_A4_1228.xlsx, BOM_PCBABeagleV_StarLight_B2_Design.xlsx, BeagleV v0.9.DSN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]
2021-04-22 add gerbers
    [art_param.txt, nc_param.txt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]
2021-05-22 add old tests for Linux 4.19 and u-boot 2018.9
    These old factory test instructions may be useful to those that had
    asked about CSI camera and DSI display
    This was tested by Seeed during manufacturing using older u-boot 2018.9
    and Linux 4.19. Some of this functionality is not yet working in the
    current Linux 5.10+ and u-boot 2021.01 repo.
    Thus for reference:
    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
2021-05-22 rename test report dir for old beta prototype
2021-07-30 move repo into archived status as the project is now over
    [BOM_PCBABeagleV_StarLight_B2_Design.xlsx, BeagleV v0.9.DSN]
